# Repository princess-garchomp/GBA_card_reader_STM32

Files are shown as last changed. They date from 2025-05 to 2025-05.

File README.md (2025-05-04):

In high school I had this idea of a thing I wanted to build. I wanted to make a thing that got roms out of GBA cartridges. 
I had no idea what knowledge I needed to gain to be able to execute on it. two degrees and three employers latter I knew enough to start this project. 
at this point, people have figured out this problem almost completely. but I still wanted to do it myself. 

I got my solution to the point of reading data out of the roms but then lost intereset, I had completed most of what I wanted to. 
because this problem has been solved by others, I did not need to get funcitong game files just some meaningfull data indicating my sytem worked.

partly I gave up to spend time looking for a new job.
now that I am not on the search for a better job, I am going to re-start this project. 

inital commits are what I found on my computer that I think were relevant. there may be more.

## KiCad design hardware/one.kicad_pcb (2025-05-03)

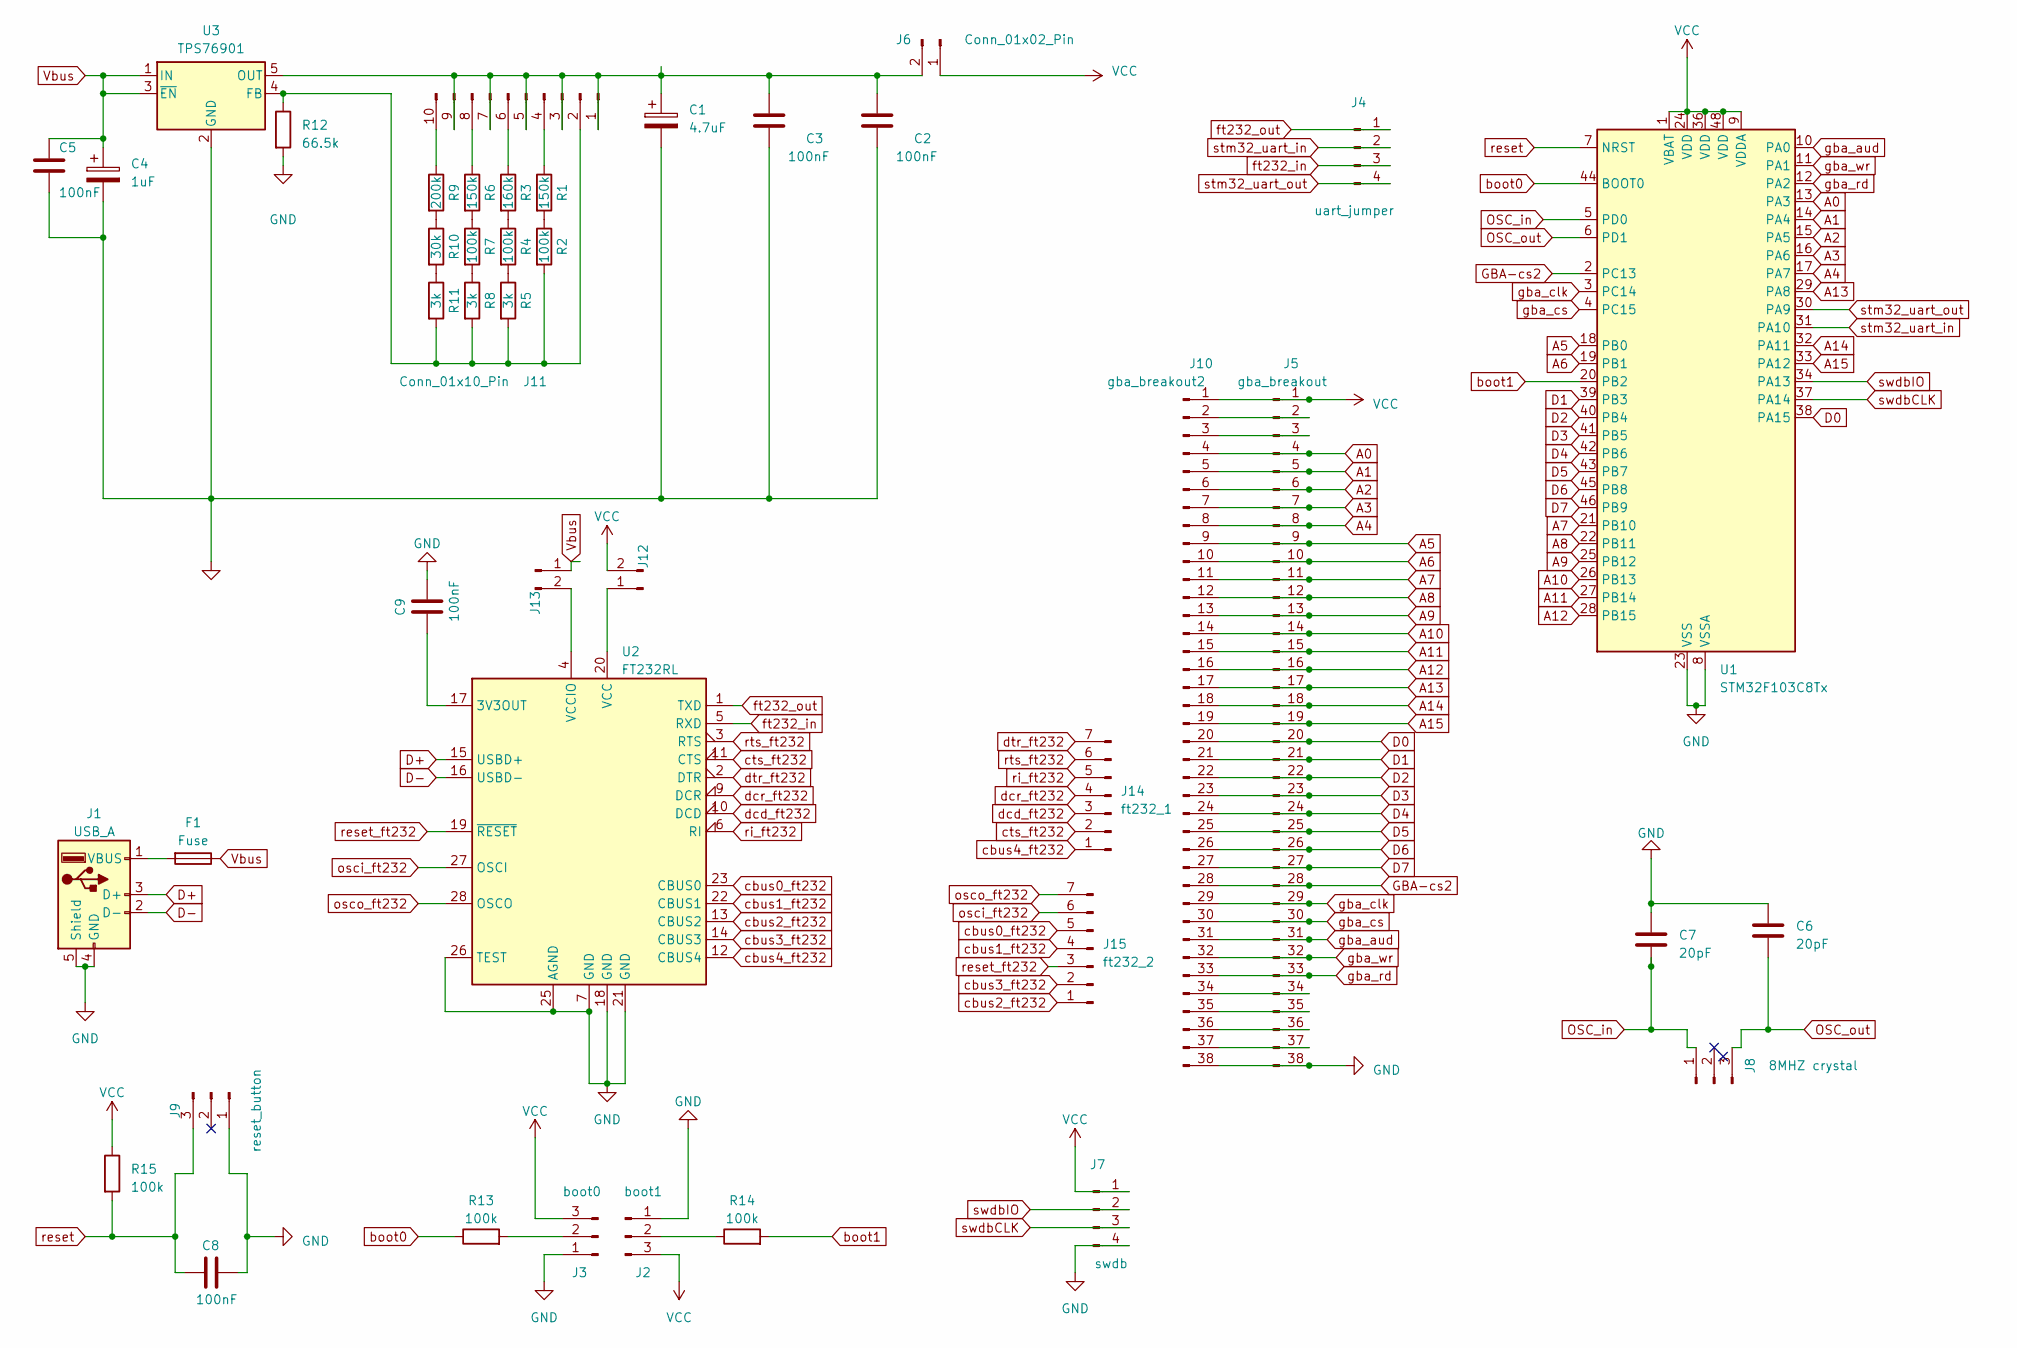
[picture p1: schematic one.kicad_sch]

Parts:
C1: 4.7uF; CP_EIA-3528-21_Kemet-B; LCSC C918865
C2, C3, C5, C8, C9: 100nF; C_0402_1005Metric; LCSC C338032
C4: 1uF; CP_EIA-3216-18_Kemet-A; LCSC C116269
C6, C7: 20pF; C_0402_1005Metric; LCSC C882568
F1: Fuse; Fuse_1206_3216Metric; LCSC C2836286
J1: USB_A; USB_A_Molex_67643_Horizontal
J2: boot1; PinSocket_1x03_P2.54mm_Vertical
J3: boot0; PinSocket_1x03_P2.54mm_Vertical
J4: uart_jumper; PinSocket_1x04_P2.54mm_Vertical
J5: gba_breakout; PinHeader_1x38_P2.54mm_Vertical
J6, J12, J13: Conn_01x02_Pin; PinHeader_1x02_P2.54mm_Vertical
J7: swdb; PinSocket_1x04_P2.54mm_Vertical
J8: 8MHZ crystal; PinSocket_1x03_P2.54mm_Vertical
J9: reset_button; PinSocket_1x03_P2.54mm_Vertical
J10: gba_breakout2; PinHeader_1x38_P2.54mm_Vertical
J11: Conn_01x10_Pin; PinSocket_1x10_P2.54mm_Vertical
J14: ft232_1; PinSocket_1x07_P2.54mm_Vertical
J15: ft232_2; PinSocket_1x07_P2.54mm_Vertical
R1, R6: 150k; R_0402_1005Metric; LCSC C429049
R2, R4, R7, R13, R14, R15: 100k; R_0402_1005Metric; LCSC C279979
R3: 160k; R_0402_1005Metric; LCSC C423115
R5, R8, R11: 3k; R_0402_1005Metric; LCSC C144761
R9: 200k; R_0402_1005Metric; LCSC C208822
R10: 30k; R_0402_1005Metric; LCSC C352437
R12: 66.5k; R_0402_1005Metric; LCSC C227185
U1: STM32F103C8Tx; LQFP-48_7x7mm_P0.5mm; LCSC C8734
U2: FT232RL; SSOP-28_5.3x10.2mm_P0.65mm; LCSC C8690
U3: TPS76901; SOT-23-5; LCSC C13997

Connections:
A0: J5.4, J10.4, U1.13 (PA3)
A1: J5.5, J10.5, U1.14 (PA4)
A2: J5.6, J10.6, U1.15 (PA5)
A3: J5.7, J10.7, U1.16 (PA6)
A4: J5.8, J10.8, U1.17 (PA7)
A5: J5.9, J10.9, U1.18 (PB0)
A6: J5.10, J10.10, U1.19 (PB1)
A7: J5.11, J10.11, U1.21 (PB10)
A8: J5.12, J10.12, U1.22 (PB11)
A9: J5.13, J10.13, U1.25 (PB12)
A10: J5.14, J10.14, U1.26 (PB13)
A11: J5.15, J10.15, U1.27 (PB14)
A12: J5.16, J10.16, U1.28 (PB15)
A13: J5.17, J10.17, U1.29 (PA8)
A14: J5.18, J10.18, U1.32 (PA11)
A15: J5.19, J10.19, U1.33 (PA12)
D0: J5.20, J10.20, U1.38 (PA15)
D1: J5.21, J10.21, U1.39 (PB3)
D2: J5.22, J10.22, U1.40 (PB4)
D3: J5.23, J10.23, U1.41 (PB5)
D4: J5.24, J10.24, U1.42 (PB6)
D5: J5.25, J10.25, U1.43 (PB7)
D6: J5.26, J10.26, U1.45 (PB8)
D7: J5.27, J10.27, U1.46 (PB9)
D+: J1.3 (D+), U2.15 (USBD+)
D-: J1.2 (D-), U2.16 (USBD-)
GBA-cs2: J5.28, J10.28, U1.2 (PC13)
GND: C1.2, C2.2, C3.2, C4.2, C5.2, C6.1, C7.1, C8.2, C9.2, J1.4 (GND), J1.5 (Shield), J2.1, J3.1, J5.38, J7.4, J9.1, J10.38, R12.2, U1.8 (VSSA), U1.23 (VSS), U1.35 (VSS), U1.47 (VSS), U2.7 (GND), U2.18 (GND), U2.21 (GND), U2.25 (AGND), U2.26 (TEST), U3.2 (GND); also elsewhere on the board
unnamed: F1.2, J1.1 (VBUS)
unnamed: J2.2, R14.1
unnamed: J3.2, R13.2
unnamed: J5.2, J10.2
unnamed: J5.3, J10.3
unnamed: J5.34, J10.34
unnamed: J5.35, J10.35
unnamed: J5.36, J10.36
unnamed: J5.37, J10.37
unnamed 37: C1.1, C2.1, C3.1, J6.2, J11.1, J11.3, J11.5, J11.7, J11.9, U3.5 (OUT); also elsewhere on the board
unnamed: J11.2, R2.2, R5.2, R8.2, R11.2, R12.1, U3.4 (FB)
unnamed: J11.4, R1.1
unnamed: J11.6, R3.1
unnamed: J11.8, R6.1
unnamed: J11.10, R9.1
unnamed: J12.1, U2.20 (VCC)
unnamed: J13.2, U2.4 (VCCIO)
unnamed: R1.2, R2.1
unnamed: R3.2, R4.1
unnamed: R4.2, R5.1
unnamed: R6.2, R7.1
unnamed: R7.2, R8.1
unnamed: R9.2, R10.1
unnamed: R10.2, R11.1
unnamed: C9.1, U2.17 (3V3OUT)
OSC_in: C7.2, J8.1, U1.5 (PD0)
OSC_out: C6.2, J8.3, U1.6 (PD1)
VCC: J2.3, J3.3, J5.1, J6.1, J7.1, J10.1, J12.2, R15.1, U1.1 (VBAT), U1.9 (VDDA), U1.24 (VDD), U1.36 (VDD), U1.48 (VDD); also elsewhere on the board
Vbus: C4.1, C5.1, F1.1, J13.1, U3.1 (IN), U3.3 (~EN)
boot0: R13.1, U1.44 (BOOT0)
boot1: R14.2, U1.20 (PB2)
cbus0_ft232: J15.5, U2.23 (CBUS0)
cbus1_ft232: J15.4, U2.22 (CBUS1)
cbus2_ft232: J15.1, U2.13 (CBUS2)
cbus3_ft232: J15.2, U2.14 (CBUS3)
cbus4_ft232: J14.1, U2.12 (CBUS4)
cts_ft232: J14.2, U2.11 (CTS)
dcd_ft232: J14.3, U2.10 (DCD)
dcr_ft232: J14.4, U2.9 (DCR)
dtr_ft232: J14.7, U2.2 (DTR)
ft232_in: J4.3, U2.5 (RXD)
ft232_out: J4.1, U2.1 (TXD)
gba_aud: J5.31, J10.31, U1.10 (PA0)
gba_clk: J5.29, J10.29, U1.3 (PC14)
gba_cs: J5.30, J10.30, U1.4 (PC15)
gba_rd: J5.33, J10.33, U1.12 (PA2)
gba_wr: J5.32, J10.32, U1.11 (PA1)
osci_ft232: J15.6, U2.27 (OSCI)
osco_ft232: J15.7, U2.28 (OSCO)
reset: C8.1, J9.3, R15.2, U1.7 (NRST); also elsewhere on the board
reset_ft232: J15.3, U2.19 (~RESET)
ri_ft232: J14.5, U2.6 (RI)
rts_ft232: J14.6, U2.3 (RTS)
stm32_uart_in: J4.2, U1.31 (PA10)
stm32_uart_out: J4.4, U1.30 (PA9)
swdbCLK: J7.3, U1.37 (PA14)
swdbIO: J7.2, U1.34 (PA13)

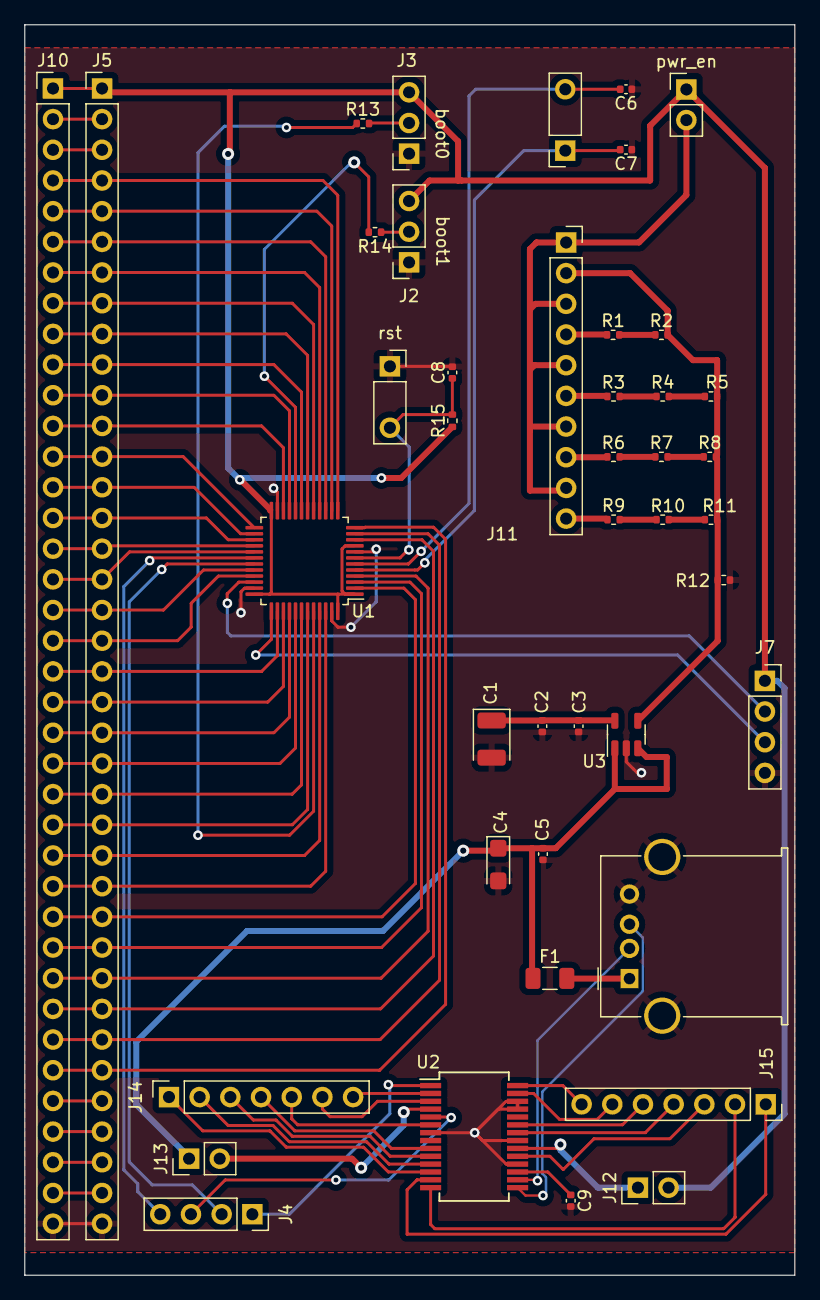
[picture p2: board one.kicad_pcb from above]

Board: 2 copper layers, 63.8 x 103.5 mm, 43 parts (0 on the bottom side), 85 nets.

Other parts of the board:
pwr_en: Conn_01x02_Pin; PinHeader_1x02_P2.54mm_Vertical
rst: reset_button; PinSocket_1x03_P2.54mm_Vertical

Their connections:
GND: rst.1; also elsewhere on the board
unnamed 37: pwr_en.2; also elsewhere on the board
VCC: pwr_en.1; also elsewhere on the board
reset: rst.3; also elsewhere on the board

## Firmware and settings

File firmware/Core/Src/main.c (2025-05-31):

#include "GPIO.h"
#include "CLOCK.h"
#include "UART.h"
#include "CART_READ.h"
#include "UART_TO_USB_COMM.h"
#include "CRC.h"
#include "configuration.h"

void big_test_foo();

int main(void)
{
	//UGLY_configuration_init();
	gpio_pin_one_output_config();
	gpio_pin_two_input_config();
	init_CRC();

	enable_PLL_sysclock_src_external_HSE_PLL_src();
	config_systic_for_ms(72000);//72000000 would result in 1ms interrutps on the systick. so lets change it to us by removing 3 zeroes
	init_IO();
	set_cart_rom_pins_output();
	config_UART1_blocking_115200baud();

	while (1)
	{
		//UGLY_coniguration_main_foo();
		(void) big_test_foo();

	}
}

big_test_foo()
{
	static uint16_t tempWord=0;
	static uint32_t cartSize = 8192000;
	//static uint32_t cartSize = 8704000;


	//for (uint32_t myAddress = 0; myAddress < cartSize; myAddress += 512)
	for (uint32_t myAddress = 0; myAddress < cartSize; myAddress += 1024)

	//for (uint32_t myAddress = 298712; myAddress < cartSize; myAddress += 30)
	{
		(void) UART_BYTE_recieve_blocking(USART1);
		//for (int currWord = 0; currWord < 12; currWord += 2)
		//for (int currWord = 0; currWord < 512; currWord += 2)
		for (int currWord = 0; currWord < 1024; currWord += 2)
		{

			tempWord = read_rom_word(myAddress + currWord);
			UART_BYTE_send_blocking(USART1, tempWord);
			tempWord = (tempWord>>8);
			UART_BYTE_send_blocking(USART1, tempWord);
		}
	}

}

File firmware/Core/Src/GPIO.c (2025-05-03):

#include "GPIO.h"

#define TWO_CONFIG_BITS(X)			X*2

#define PA12_CNF_OFFSET				18
#define PA12_MODE_OFFSET			16
#define PA12_ODR_OFFSET				12

#define PA2_CNF_OFFSET				10
#define PA2_MODE_OFFSET				8
#define PA2_ODR_IDR_OFFSET			2

//GPIOx_CRL and GPIOx_CRH
#define CNF_OUTPUT_PUSH_PULL		0b00
#define CNF_OUTPUT_OPEN_DRAIN		0b01
#define CNF_INPUT_FLOATING			0b01
#define CNF_INPUT_PULL_DOWN			0b10
#define CNF_INPUT_PULL_UP			0b10

#define MODE_NONE					0b00
#define MODE_SPEED_10MHZ			0b01
#define MODE_SPEED_2MHZ				0b10
#define MODE_SPEED_50MHZ			0b11

//GPIOx_ODR
#define ODR_INPUT_PULL_UP			0b1
#define ODR_INPUT_PULL_DOWN			0b0
#define ODR_OUTPUT_ON				0b1
#define ODR_OUTPUT_OFF				0b0

//GPIOx_IDR
#define IDR_INPUT_ON				0b1
#define IDR_INPUT_OFF				0b0




//configuration masks:
#define CRL_A_IO_MASK				(GPIO_CRL_MODE0_Msk|GPIO_CRL_CNF0_Msk|GPIO_CRL_MODE3_Msk|GPIO_CRL_CNF3_Msk|GPIO_CRL_MODE4_Msk|GPIO_CRL_CNF4_Msk|GPIO_CRL_MODE5_Msk|GPIO_CRL_CNF5_Msk|GPIO_CRL_MODE6_Msk|GPIO_CRL_CNF6_Msk|GPIO_CRL_MODE7_Msk|GPIO_CRL_CNF7_Msk)
#define CRH_A_IO_MASK				(GPIO_CRH_MODE8_Msk|GPIO_CRH_CNF8_Msk|GPIO_CRH_MODE11_Msk|GPIO_CRH_CNF11_Msk|GPIO_CRH_MODE12_Msk|GPIO_CRH_CNF12_Msk)
#define CRL_B_IO_MASK				(GPIO_CRL_MODE0_Msk|GPIO_CRL_CNF0_Msk|GPIO_CRL_MODE1_Msk|GPIO_CRL_CNF1_Msk|GPIO_CRL_MODE2_Msk|GPIO_CRL_CNF2_Msk|GPIO_CRL_MODE4_Msk|GPIO_CRL_CNF4_Msk|GPIO_CRL_MODE5_Msk|GPIO_CRL_CNF5_Msk|GPIO_CRL_MODE6_Msk|GPIO_CRL_CNF6_Msk|GPIO_CRL_MODE7_Msk|GPIO_CRL_CNF7_Msk)
#define CRH_B_IO_MASK				(GPIO_CRH_MODE8_Msk|GPIO_CRH_CNF8_Msk|GPIO_CRH_MODE9_Msk|GPIO_CRH_CNF9_Msk|GPIO_CRH_MODE10_Msk|GPIO_CRH_CNF10_Msk|GPIO_CRH_MODE11_Msk|GPIO_CRH_CNF11_Msk|GPIO_CRH_MODE12_Msk|GPIO_CRH_CNF12_Msk|GPIO_CRH_MODE13_Msk|GPIO_CRH_CNF13_Msk|GPIO_CRH_MODE14_Msk|GPIO_CRH_CNF14_Msk|GPIO_CRH_MODE15_Msk|GPIO_CRH_CNF15_Msk)
#define CRH_C_IO_MASK				(GPIO_CRH_MODE13_Msk|GPIO_CRH_CNF13_Msk)






/////////////////////////////////////////////////////////////////////////////////////////////////////
//write rom address masks:
#define CRX_PUSH_PULL_OUTPUT_50_MHZ	(CNF_OUTPUT_PUSH_PULL|MODE_SPEED_50MHZ)//this is 4 pits long

#define PA0_CRH_OUTPUT_CONFIG		(CRX_PUSH_PULL_OUTPUT_50_MHZ<<GPIO_CRL_MODE0_Pos)
#define PA3_CRL_OUTPUT_CONFIG		(CRX_PUSH_PULL_OUTPUT_50_MHZ<<GPIO_CRL_MODE3_Pos)
#define PA4_CRL_OUTPUT_CONFIG		(CRX_PUSH_PULL_OUTPUT_50_MHZ<<GPIO_CRL_MODE4_Pos)
#define PA5_CRL_OUTPUT_CONFIG		(CRX_PUSH_PULL_OUTPUT_50_MHZ<<GPIO_CRL_MODE5_Pos)
#define PA6_CRL_OUTPUT_CONFIG		(CRX_PUSH_PULL_OUTPUT_50_MHZ<<GPIO_CRL_MODE6_Pos)
#define PA7_CRL_OUTPUT_CONFIG		(CRX_PUSH_PULL_OUTPUT_50_MHZ<<GPIO_CRL_MODE7_Pos)

#define PORT_A_CRL_OUTPUT_CONFIG		(PA0_CRH_OUTPUT_CONFIG|PA3_CRL_OUTPUT_CONFIG|PA4_CRL_OUTPUT_CONFIG|PA5_CRL_OUTPUT_CONFIG|PA6_CRL_OUTPUT_CONFIG|PA7_CRL_OUTPUT_CONFIG)

#define PA8_CRH_OUTPUT_CONFIG		(CRX_PUSH_PULL_OUTPUT_50_MHZ<<GPIO_CRH_MODE8_Pos)
#define PA11_CRH_OUTPUT_CONFIG		(CRX_PUSH_PULL_OUTPUT_50_MHZ<<GPIO_CRH_MODE11_Pos)
#define PA12_CRH_OUTPUT_CONFIG		(CRX_PUSH_PULL_OUTPUT_50_MHZ<<GPIO_CRH_MODE12_Pos)


#define PORT_A_CRH_OUTPUT_CONFIG		(PA8_CRH_OUTPUT_CONFIG|PA11_CRH_OUTPUT_CONFIG|PA12_CRH_OUTPUT_CONFIG)



#define PB0_CRL_OUTPUT_CONFIG		(CRX_PUSH_PULL_OUTPUT_50_MHZ<<GPIO_CRL_MODE0_Pos)
#define PB1_CRL_OUTPUT_CONFIG		(CRX_PUSH_PULL_OUTPUT_50_MHZ<<GPIO_CRL_MODE1_Pos)
#define PB2_CRL_OUTPUT_CONFIG		(CRX_PUSH_PULL_OUTPUT_50_MHZ<<GPIO_CRL_MODE2_Pos)
#define PB4_CRL_OUTPUT_CONFIG		(CRX_PUSH_PULL_OUTPUT_50_MHZ<<GPIO_CRL_MODE4_Pos)
#define PB5_CRL_OUTPUT_CONFIG		(CRX_PUSH_PULL_OUTPUT_50_MHZ<<GPIO_CRL_MODE5_Pos)
#define PB6_CRL_OUTPUT_CONFIG		(CRX_PUSH_PULL_OUTPUT_50_MHZ<<GPIO_CRL_MODE6_Pos)
#define PB7_CRL_OUTPUT_CONFIG		(CRX_PUSH_PULL_OUTPUT_50_MHZ<<GPIO_CRL_MODE7_Pos)

#define PORT_B_CRL_OUTPUT_CONFIG		(PB0_CRL_OUTPUT_CONFIG|PB1_CRL_OUTPUT_CONFIG|PB2_CRL_OUTPUT_CONFIG|PB4_CRL_OUTPUT_CONFIG|PB5_CRL_OUTPUT_CONFIG|PB6_CRL_OUTPUT_CONFIG|PB7_CRL_OUTPUT_CONFIG)

#define PB10_CRH_OUTPUT_CONFIG		(CRX_PUSH_PULL_OUTPUT_50_MHZ<<GPIO_CRH_MODE10_Pos)
#define PB11_CRH_OUTPUT_CONFIG		(CRX_PUSH_PULL_OUTPUT_50_MHZ<<GPIO_CRH_MODE11_Pos)
#define PB12_CRH_OUTPUT_CONFIG		(CRX_PUSH_PULL_OUTPUT_50_MHZ<<GPIO_CRH_MODE12_Pos)
#define PB13_CRH_OUTPUT_CONFIG		(CRX_PUSH_PULL_OUTPUT_50_MHZ<<GPIO_CRH_MODE13_Pos)
#define PB14_CRH_OUTPUT_CONFIG		(CRX_PUSH_PULL_OUTPUT_50_MHZ<<GPIO_CRH_MODE14_Pos)
#define PB15_CRH_OUTPUT_CONFIG		(CRX_PUSH_PULL_OUTPUT_50_MHZ<<GPIO_CRH_MODE15_Pos)
#define PB8_CRH_OUTPUT_CONFIG		(CRX_PUSH_PULL_OUTPUT_50_MHZ<<GPIO_CRH_MODE8_Pos)
#define PB9_CRH_OUTPUT_CONFIG		(CRX_PUSH_PULL_OUTPUT_50_MHZ<<GPIO_CRH_MODE9_Pos)

#define PORT_B_CRH_OUTPUT_CONFIG		(PB10_CRH_OUTPUT_CONFIG|PB11_CRH_OUTPUT_CONFIG|PB12_CRH_OUTPUT_CONFIG|PB13_CRH_OUTPUT_CONFIG|PB14_CRH_OUTPUT_CONFIG|PB15_CRH_OUTPUT_CONFIG|PB8_CRH_OUTPUT_CONFIG|PB9_CRH_OUTPUT_CONFIG)


#define PC13_CRH_OUTPUT_CONFIG		(CRX_PUSH_PULL_OUTPUT_50_MHZ<<GPIO_CRH_MODE13_Pos)

#define PORT_C_CRH_OUTPUT_CONFIG	(PC13_CRH_OUTPUT_CONFIG)
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

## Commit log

2025-05-03 inital commit from work done in ~2023 I remember needing to do a lot of hardware mods to get things working I remember reading stuff out of the rom and having it print in a putty terminal I am not su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
    [configuration.h, one.kicad_pcb, one.kicad_sch]
2025-05-03 cleaning things up. the ugly way I was testing drivers is now put into its own C/H file.
    [configuration.h]
2025-05-04 python talking to my board and getting most of the rom out, still debugging
